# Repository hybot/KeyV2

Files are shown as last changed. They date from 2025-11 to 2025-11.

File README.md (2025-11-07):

# Parametric Mechanical Keycap Library

a slightly askew welcome picture

### Nov 5, 2025

Forked from rsheldiii/KeyV2:master to rename vars and modules with a leading digit in their names,
as that is now deprecated in nightly builds, and generates a ton of warnings.

Note that "customizer.scad" is still horribly broken in development builds. This stems from a
basic change in how the developer builds work, and how customizer.scad is generated, which assumes
these warnings will be ignored or not generated. Since this file is primarily for use in the
Thingiverse customizer, which uses an ancient, basterdized version of OpenSCAD, I've left it alone.

So if you're reading this, ignore the instructions in the original README (below) on using OpenSCAD
Customizer. Insted use the "recommended way", editing "keys.scad" (or a copy of it), which works
fine now, and only requires minimal coding to get you custom keys.

There are no other changes to existing files, though there is a new file, "hybot_keys.scad",
edited from keys.scad, which can serve as an additonal example, plus adds more customizer options.
There is also a screenshot for it:
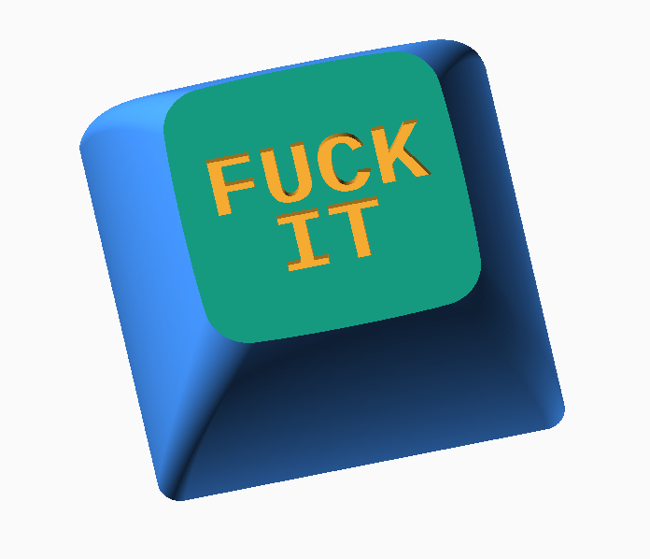
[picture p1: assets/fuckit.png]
Fuck It key for Central Computers' 39th anniversary key chain


The the settings in hybot_keys.scad are intended for an SLA (resin) printer, especially $fn and
possibly the font size, and are probably not suitable for an FDM printer. If you don't have a fast
computer it may take 10 to 20 seconds for the first render.

---

This library is a keycap and keyset construction library for mechanical keyboards, written in openSCAD.

Relevant links:
* Thingiverse: https://www.thingiverse.com/thing:2783650
* Shapeways: https://www.shapeways.com/designer/rsheldiii/creations
* Buy me a coffee: https://ko-fi.com/rsheldiii, but only if you want to!

# V2.0.0 Cutover

As of February 19th, 2022, the v2.0.0 branch has been merged into master.

This branch completely rewrote key.scad to be much simpler and faster. If you're just starting out, please use master and report any bugs you find.

If you branched off this repo previously, merging to master will probably break any additions you've made. If you need the prior version of the code for whatever reason, v1.1.0 is master just before the v2.0.0 merge. I will be backporting bugfixes to the v1 branch, so if you see v1.1.1 or higher, use that instead.

## How to run

#### OpenSCAD Proper (recommended way)

If you are technically inclined at all, this is definitely the best way to run the code. It's not very hard!

First, you'll need OpenSCAD: http://www.openscad.org/downloads.html. I highly recommend installing the development snapshot, as they generally support more features and are relatively stable. Development snapshots are listed in their own section on the downloads page.

After you have openSCAD installed, you need to download the code and run it. running `git clone https://github.com/rsheldiii/openSCAD-projects.git` if you have git, or downloading [this zip](https://github.com/rsheldiii/openSCAD-projects/archive/master.zip) and extracting the directory should do it. 

To make your own key, all you need to do is open `keys.scad` with openSCAD and modify this line:

```
dcs_row(5) legend("⇪", size=9) key();
``` 

To be whatever you want. For example, this is for a ctrl key on an OEM keyboard:  

```u(1.25) oem_row(3) legend("ctrl", size=4.5) key();```

It is possible to edit this project with an external editor by checking off Design => 'Automatic Reload and Preview' in OpenSCAD.

All examples below assume you are running the library on your computer with OpenSCAD.

#### OpenSCAD Customizer

If you're not technically inclined enough to start programming in OpenSCAD (it's easier than you think), you can look into [getting OpenSCAD's customizer working](https://github.com/rsheldiii/KeyV2/wiki/Getting-the-OpenSCAD-Customizer-working).

`customizer.scad` is auto-generated from the other files in this repository due to a quirk with how OpenSCAD shows customizer settings. It should be perpetually kept up to date, but there may be some bugs. feel free to open an issue if you find one!

#### Thingiverse Customizer

The easiest and buggiest way to run this program is to boot it up in [Thingiverse's Customizer](https://www.thingiverse.com/apps/customizer/run?thing_id=2783650). Explanations of each option are provided, as well as some default variables. Twiddle the variables to see how the keycap changes!

Unfortunately I don't think I can update the Thingiverse customizer without breaking it, so you don't get all the cool new features I've been developing over the past couple years.

## High-level overview

This library supports Cherry and Alps switches, and has pre-defined key profiles for SA, DSA, DCS, G20, Hi-Pro and (some form of) OEM keycaps. `keys.scad` is the entry point for everything but the most technical use. Pre-programmed key profiles can be found in the `key_profiles` directory.

Every key starts with default settings (provided in `settings.scad`) that are overridden by each function call. The simplest key you can make would be:

```
key();
```
![a bog-standard cherry key](assets/example1.JPG)

which is a bog-standard DCS row 5 (number / function row) keycap. To change how the key is generated, you can modify the settings directly or add predefined modifier functions like so:

```
// directly modified setting
$stem_inset = 1;
// settings changed through modifier function
sa_row(2) 2u() key();
```

You can chain as many modifier functions as you like!

![a 2 unit SA row 2 cherry key](assets/example2.JPG)

## Modifier functions

There is a bevy of supporting functions to customize your keycaps. You can add a brim to more easily print the stem with `brimmed_stem_support`, make 2x2 keycaps with `2u() 2uh()`, add legends, rotate stems, and more. All these functions manipulate the settings available to you in [`settings.scad`](https://github.com/rsheldiii/KeyV2/blob/master/src/settings.scad), though [some of them](https://github.com/rsheldiii/KeyV2/blob/851ececdb297c77bfbcd0a7cb4cdbc5e21970396/src/key_transformations.scad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) are quite complex.

These modifier functions can be found in [`key_profiles/`](https://github.com/rsheldiii/KeyV2/blob/master/src/key_profiles) for different keycap profiles, [`key_types.scad`](https://github.com/rsheldiii/KeyV2/blob/master/src/key_types.scad) for predefined settings for common keys (spacebar, left shift, etc), [`key_sizes.scad`](https://github.com/rsheldiii/KeyV2/blob/master/src/key_sizes.scad) for common unit sizes, and [`key_transformations.scad`](https://github.com/rsheldiii/KeyV2/blob/master/src/key_transformations.scad) for everything else. I encourage you to do some sleuthing but for a list of (most) helper functions with explanations, [Check out the wiki!](https://github.com/rsheldiii/KeyV2/wiki/KeyV2-Helper-Documentation)

These modifier functions may not cover every use case; in that case, you may have to write some SCAD yourself.

## Layouts

new to the library and still in a beta state, layouts allows you to generate an entire layout for a keyboard!

It is recommended to print layouts with a brim that extends to the next key.

```
60_percent_default("dcs") key();
```

![a standard 60 percent layout](assets/layout.png)

layouts accept children, so you can use them as a chained function like other modifiers. Be wary of accidentally overriding something the layout does for you though.

#### Example customizations

Let's say you wanted to generate some 2u stabilized keycaps for an Ergodox, you could do something like this:

```
legends = ["Enter", "Escape", "Tab", "Shift"];
for(y=[0:3]) {
  translate_u(0,y) 2u() dsa_row() stabilized() cherry() legend(legends[y], [0,0, 6]) key();
}
```

![a set of 2 unit keys with legends](assets/example3.JPG)

The `key()` function also supports children, and will place them in the center of the top of the keycap, if you want to quickly design your own artisan keycaps:

```
cherry() key() {
  translate([-6.25,2.3,-0]) scale(0.074) import("Assieme1.stl");
};
```

![an artisan key with no-face on it](assets/example4.JPG)

(no face courtesy of [this thing](https://www.thingiverse.com/thing:519727/))

Artisan support also supports _subtracting_ children by doing `key(inset=true) { ... }`, which is super helpful if you want to make keycaps with legends that are not text. The children will be placed just above the middle of the dish as per usual; you will need to translate them downwards (`ex translate([0,0,-1])`) to get them to 'dig in' to the top of the key.

## Tips and tricks

Looking for information or something specific? you could try checking out the [tips and tricks](TIPS_AND_TRICKS.md) section, or the [examples](/examples) directory.

## What if I want to get _really_ technical?

Now we're talkin!

At the base level this project should function well as an intensive key profile design library. by loading up `src/key.scad` (notice no s) you can tweak variables in `src/settings.scad` to prototype your own profiles. `key.scad` There are currently ~~44~~ a lot of different settings to tweak in `src/settings.scad` including width height and depth of the keycap, dish tilt, top skew, fonts, wall thickness, etc. If you want to see the full list of settings, feel free to browse the file itself: [settings.scad](https://github.com/rsheldiii/KeyV2/blob/master/src/settings.scad) it has lots of comments to help you get started.

This library should also be abstract enough to handle new dish types, keystems, key layouts, key profiles, and key shapes, in case you want to design your own Typewriter-style keycaps, support buckling spring keyboards or design some kind of triangular dished profile. `src/shapes.scad` `src/stems.scad` and `src/dishes.scad` all have a 'selector' module that should allow you to implement your own creations alongside what already exists in their constituent folders.

If you're interested in this, it may help to read the [Technical Design of a keycap](https://github.com/rsheldiii/KeyV2/wiki/Technical-Design-of-a-Keycap) wiki page.

Here's an example of tweaking the settings and code to make a 'stop sign' key profile:

In `key_shape()` in `shapes.scad`:

```
 else if ($key_shape_type == "stop_sign") {
   stop_sign_shape(size, delta, progress);
 }
```

in `src/shapes/stop_sign.scad`:

```
module stop_sign_shape(size, delta, progress){
  rotate([0,0,22.5]) circle(d=size[0] - delta[0], $fn=8);
}
```

In `keys.scad`:

```
union() {
  // make the font smaller
  $font_size = 3;
  // top of keycap is the same size as the bottom
  $width_difference = 0;
  $height_difference = 0;
  $key_shape_type="stop_sign";
  $dish_type = "cylindrical";
  // some keycap tops are slid backwards a little, and we don't want that
  $top_skew = 0;

  legends = ["Stop..", "Hammer", "time!"];

  for(x=[0:len(legends)-1]) {
    translate_u(x) cherry() key(legends[x]);
  }
}
```

![three stop-sign shaped keys with legends](assets/example5.JPG)

## Printing Help

Prints from this library are still challenging, despite all efforts to the contrary. Resin printers can create great looking keycaps; FDM printers can create usable keys that look alright, but may require tweaking to get prints acceptable. There are a few quick things that you can do:

1. If your stem isn't fitting in the switch, try upping the slop factor, accessed by giving your keystem function a numeric value (eg `cherry(0.5) key()`). This will lengthen the cross and decrease the overall size of the keystem. The default value is 0.3, and represents millimeters. Note that even if you have a resin printer, you should probably keep the default value; keys printed with 0 slop will barely fit on the stem.

2. If your keystem breaks off the bed mid-print, you can enable a brim by adding the `brimmed_stem_support()` modifier. This will give a solid base for the keystem to anchor into.

3. If you are unsatisfied with the quality of the top surface, you can try printing the keycap on a different surface than the bottom, though it may impact the quality of the stem.

4. If your newly-designed key shape is crashing into the switch, you can enable a clearance check for cherry switches by adding `$clearance_check = true;` to your keycap declaration. This will subtract a cherry switch shape from your keycap, highlighting any parts in red which intersect with the switch.

That's it, if you have any questions feel free to open an issue or leave a comment on thingiverse!

## TODO:
moved to [TODO doc](./TODO.md)

## Contributions welcome

 My lists of key profiles and layouts are not exhaustive at all, if you want to contribute feel free to make a PR with your changes and we can work together on getting it merged!

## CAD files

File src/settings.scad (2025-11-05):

/* [Basic-Settings] */

// Length in units of key. A regular key is 1 unit; spacebar is usually 6.25
$key_length = 1.0; // Range not working in thingiverse customizer atm [1:0.25:16]

// What type of stem you want. Most people want Cherry.
$stem_type = "cherry";  // [cherry, alps, rounded_cherry, box_cherry, filled, disable]

// The stem is the hardest part to print, so this variable controls how much 'slop' there is in the stem
// if your keycaps stick in the switch raise this value
$stem_slop = 0.35; // Not working in thingiverse customizer atm [0:0.01:1]
// broke this out. if your keycaps are falling off lower this value. only works for cherry stems rn
$stem_inner_slop = 0.2;

// Font size used for text
$font_size = 6;

// Set this to true if you're making a spacebar!
$inverted_dish = false;

// change aggressiveness of double sculpting
// this is the radius of the cylinder the keytops are placed on
$double_sculpt_radius = 200;


// Support type. default is "flared" for easy FDM printing; bars are more realistic, and flat could be for artisans
$support_type = "flared"; // [flared, bars, flat, disable]

// Supports for the stem, as it often comes off during printing. Reccommended for most machines
$stem_support_type = "tines"; // [tines, brim, disabled]

// make legends outset instead of inset.
// broken off from artisan support since who wants outset legends?
$outset_legends = false;

/* [Key] */
// Height in units of key. should remain 1 for most uses
$key_height = 1.0;
// Keytop thickness, aka how many millimeters between the inside and outside of the top surface of the key
$keytop_thickness = 1;
// Wall thickness, aka the thickness of the sides of the keycap. note this is the total thickness, aka 3 = 1.5mm walls
$wall_thickness = 3;
// Radius of corners of keycap
$corner_radius = 1;
// Width of the very bottom of the key
$bottom_key_width = 18.16;
// Height (from the front) of the very bottom of the key
$bottom_key_height = 18.16;
// How much less width there is on the top. eg top_key_width = bottom_key_width - width_difference
$width_difference = 6;
// How much less height there is on the top
$height_difference = 4;
// How deep the key is, before adding a dish
$total_depth = 11.5;
// The tilt of the dish in degrees. divided by key height
$top_tilt = -6;
// the y tilt of the dish in degrees. divided by key width.
// for double axis sculpted keycaps and probably not much else
$top_tilt_y = 0;
// How skewed towards the back the top is (0 for center)
$top_skew = 1.7;

// how skewed towards the right the top is. unused, but implemented.
// for double axis sculpted keycaps and probably not much else
$top_skew_x = 0;

/* [Stem] */

// How far the throw distance of the switch is. determines how far the 'cross' in the cherry switch digs into the stem, and how long the keystem needs to be before supports can start. luckily, alps and cherries have a pretty similar throw. can modify to have stouter keycaps for low profile switches, etc
$stem_throw = 4;
// Diameter of the outside of the rounded cherry stem
$rounded_cherry_stem_d = 5.5;


// How much higher the stem is than the bottom of the keycap.
// Inset stem requires support but is more accurate in some profiles
// can be negative to make outset stems!
$stem_inset = 0;
// How many degrees to rotate the stems. useful for sideways keycaps
$stem_rotation = 0;
// How many degrees to rotate the keycap, but _not_ inside features (the stem). 
$keycap_rotation = 0;

/* [Shape] */

// Key shape type, determines the shape of the key. default is 'rounded square'
$key_shape_type = "rounded_square";
// ISO enter needs to be linear extruded NOT from the center when not using skin. this tells the program how far up 'not from the center' is
$linear_extrude_height_adjustment = 0;
// How many slices will be made, to approximate curves on corners. Leave at 1 if you are not curving corners
// If you're doing fancy bowed keycap sides, this controls how many slices you take
$height_slices = 1;

/* [Dish] */

// What type of dish the key has. note that unlike stems and supports a dish ALWAYS gets rendered.
$dish_type = "cylindrical"; // [cylindrical, spherical, sideways cylindrical, old spherical, disable]
// How deep the dish 'digs' into the top of the keycap. this is max depth, so you can't find the height from total_depth - dish_depth. besides the top is skewed anyways
$dish_depth = 1;
// How skewed in the x direction the dish is
$dish_skew_x = 0;
// How skewed in the y direction (height) the dish is
$dish_skew_y = 0;


$dish_offset_x = 0;

// If you need the dish to extend further, you can 'overdraw' the rectangle it will hit. this was mostly for iso enter and should be deprecated
$dish_overdraw_width = 0;
// Same as width but for height
$dish_overdraw_height = 0;

/* [Misc] */
// There's a bevel on the cherry stems to aid insertion / guard against first layer squishing making a hard-to-fit stem.
$cherry_bevel = true;

// How tall in mm the stem support is, if there is any. stem support sits around the keystem and helps to secure it while printing.
$stem_support_height = .8;
// Font used for text
$font="DejaVu Sans Mono:style=Book";
// Whether or not to render fake keyswitches to check clearances
$clearance_check = false;
// Should be faster, also required for concave shapes

// what kind of extrusion we use to create the keycap. "hull" is standard, "linear extrude" is legacy, "skin" is new and not well supported.
$hull_shape_type = "hull"; // ["hull", "linear extrude", "skin"]

// This doesn't work very well, but you can try
$rounded_key = false;
//minkowski radius. radius of sphere used in minkowski sum for minkowski_key function. 1.75 for G20
$minkowski_radius = .33;

/* [Features] */

//insert locating bump
$key_bump = false;
//height of the location bump from the top surface of the key
$key_bump_depth = 0.5;
//distance to move the bump from the front edge of the key
$key_bump_edge = 0.4;

/* [Hidden] */

// set this to true if you are making double sculpted keycaps
$double_sculpted = false;

//list of legends to place on a key format: [text, halign, valign, size]
//halign = "left" or "center" or "right"
//valign = "top" or "center" or "bottom"
// Currently does not work with thingiverse customizer, and actually breaks it
$legends = [];

//list of front legends to place on a key format: [text, halign, valign, size]
//halign = "left" or "center" or "right"
//valign = "top" or "center" or "bottom"
// Currently does not work with thingiverse customizer, and actually breaks it
$front_legends = [];

// print legends on the front of the key instead of the top
$front_print_legends = false;

// how recessed inset legends / artisans are from the top of the key
$inset_legend_depth = 0.2;

// Dimensions of alps stem
$alps_stem = [4.45, 2.25];

// Dimensions of choc stem
$choc_stem = [1.2, 3];

// Enable stabilizer stems, to hold onto your cherry or costar stabilizers
$stabilizer_type = "costar_stabilizer"; // [costar_stabilizer, cherry_stabilizer, disable]

// Ternaries are ONLY for customizer. they will NOT work if you're using this in
// OpenSCAD. you should use stabilized(), openSCAD customizer,
// or set $stabilizers directly
// Array of positions of stabilizers
$stabilizers = $key_length >= 6 ? [[-50, 0], [50, 0]] : $key_length >= 2 ? [[-12,0],[12,0]] : [];

// Where the stems are in relation to the center of the keycap, in units. default is one in the center
// Shouldn't work in thingiverse customizer, though it has been...
$stem_positions = [[0,0]];

// colors
$primary_color = [.2667,.5882,1];
$secondary_color = [.4412, .7, .3784];
$tertiary_color = [1, .6941, .2];
$quaternary_color = [.4078, .3569, .749];
$warning_color = [1,0,0, 0.15];

// how many facets circles will have when used in these features
$minkowski_facets = 30;
$shape_facets =30;



// "flat" / "dished" / "disable"
$inner_shape_type = "flat";

// default side_sculpting function, linear
$side_sculpting = function(progress) 0;
$corner_sculpting = function(progress) 0;

// you probably shouldn't touch this, it's internal to sculpted_square
// modify side sculpting with the $side_sculpting function in the key profile files
$more_side_sculpting_factor = 0;

// 3d surface functions (still in beta)

// 3d surface settings
// unused for now
$k3d_surface_size = 1;
// 3d surface point resolution. $k3d_surface_size / $k3d_surface_step = steps per x / y
$k3d_surface_step = 1/20;

// monotonically increasing function that distributes the points of the surface mesh
// only for polar_3d_surface right now
// if it's linear it's a grid. sin(dim) * size concentrates detail around the edges
sinusoidal_surface_distribution = function(dim,size) sin(dim) * size;
linear_surface_distribution = function(dim,size) dim;

$surface_distribution_function = sinusoidal_surface_distribution;

// the function that actually determines what the surface is.
// feel free to override, the last one wins
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

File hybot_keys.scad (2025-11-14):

// the point of this file is to be a sort of DSL for constructing keycaps.
// when you create a method chain you are just changing the parameters
// key.scad uses, it doesn't generate anything itself until the end. This
// lets it remain easy to use key.scad like before (except without key profiles)
// without having to rely on this file. Unfortunately that means setting tons of
// special variables, but that's a limitation of SCAD we have to work around

// custom settings for the key style i like (SA), with customizer options for most.

include <./includes.scad>

/* [Stem] */
$support_type = "flat"; // [flat, flared, bars, disabled]

$stem_type = "rounded_cherry";  // [cherry, alps, rounded_cherry, box_cherry, filled, disable]

$stem_support_type = "disabled"; // [tines, brim, disabled]

/* [ Legend ] */
// number of lines.  "0" for a blank key
num_lines = 2; // [0, 1, 2, 3]

// text for line 1
legend1 = "FUCK";

// text for line 2
legend2 = "IT";

// text for line 3
legend3 = "";

text_size1 = 3.0; // .1
text_size2 = 3.0; // .1
text_size3 = 3.0; // .1

position1 = [0, -.4];
position2 = [0, .5];
position3 = [0, 1];

// the line positioning is adjusted base on the number of lines chosen
// one is centered, two centered above and below the center line,
// three have the middle line centered and first and last above and below that.
//
// this assumes a font size close to 3.0.  unfortunately customizer can't deal
// with arrays with dimensions greater than 2
positions = [[[0, 0]], // blank cap
             [[0, 0]], // one line
             [[0, -.4], [0, .5]],  // two lines
             [[0, -.9], [0, 0], [0, .9]] // three lines
             ];

// you don't have to use mono spaced, but it looks nicer for multi-line keycaps
$font="DejaVu Sans Mono:style=bold";

// how deep to engrave the legends.  the libray default of .2 is too shallow for filling
$inset_legend_depth = 0.4;

/* [Misc] */
// hole for an LED below the cap to shine through.
LED_hole=false;

// mostly for resin printing, not FDM, but more than 360 will bump render time quite a bit.
$fn=360;

// my custom key, with a 1 or 2 or 3 line legend, mostly flat, with an optional LED hole
difference() {
  sa_row(3) {
    $total_depth = 9; // a short key, since it's for a keychain
    $height_slices = 40; // smoothing for resin printers
    $dish_depth=.001; // you want very flat (but not 0) or rounded, to avoid artifacts.

    if(num_lines == 0)
      key();
    if(num_lines == 1)
      legend(legend1, position=positions[1][0], size=text_size1)
        key();
    if(num_lines == 2)
      legend(legend1, position=positions[2][0], size=text_size1)
        legend(legend2, position=positions[2][1], size=text_size2)
        key();
    if(num_lines == 3)
      legend(legend1, position=positions[3][0], size=text_size1)
        legend(legend2, position=positions[3][1], size=text_size2)
        legend(legend3, position=positions[3][2], size=text_size3)
        key();
  }
  if(LED_hole) {
    translate([0, 4.25, 0]) 
      cylinder(h=10, r=1.1);
  }
}

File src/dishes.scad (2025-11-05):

include <libraries/geodesic_sphere.scad>

include <dishes/cylindrical.scad>
include <dishes/old_spherical.scad>
include <dishes/sideways_cylindrical.scad>
include <dishes/spherical.scad>
include <dishes/squared_spherical.scad>
include <dishes/squared_scoop.scad>
include <dishes/flat.scad>
include <dishes/3d_surface.scad>

//geodesic looks much better, but runs very slow for anything above a 2u
geodesic=false;

//dish selector
module  dish(width, height, depth, inverted) {
    if($dish_type == "cylindrical"){
      cylindrical_dish(width, height, depth, inverted);
    } else if ($dish_type == "spherical") {
      spherical_dish(width, height, depth, inverted);
    } else if ($dish_type == "sideways cylindrical"){
      sideways_cylindrical_dish(width, height, depth, inverted);
    } else if ($dish_type == "old spherical") {
      old_spherical_dish(width, height, depth, inverted);
    } else if ($dish_type == "3d surface") {
      k3d_surface_dish(width, height, depth, inverted);
    } else if ($dish_type == "flat") {
      flat_dish(width, height, depth, inverted);
    } else if ($dish_type == "disable") {
      // else no dish
    } else if ($dish_type == "squared spherical") {
      squared_spherical_dish(width, height, depth, inverted=inverted);
    } else if ($dish_type == "squared scoop") {
      squared_scoop_dish(width, height, depth, inverted=inverted);
    } else {
      echo("WARN: $dish_type unsupported");
    }
}

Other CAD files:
src/key_sizes.scad
examples/plate_generation.scad
src/dishes/3d_surface.scad
src/key_types.scad
src/layouts/60_percent/default.scad
src/layouts/layout.scad

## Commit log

2025-11-05 rename vars and modules to avoid leading numbers, to stop all the warnings in dev builds
    [3d_surface.scad, default.scad, dishes.scad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]
2025-11-05 my custom key for the Central Computers keychain trinket
    [hybot_keys.scad]
2025-11-07 removed example code
    [hybot_keys.scad]
2025-11-14 support for 3 lines on cap. better comments.
    [hybot_keys.scad]
